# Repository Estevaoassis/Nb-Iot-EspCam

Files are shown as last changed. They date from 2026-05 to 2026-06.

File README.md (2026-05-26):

# PROT-TIPO-PARA-CAPTURA-E-TRANSMISS-O-DE-IMAGENS-DE-BAIXA-RESOLU-O-UTILIZANDO-CAT-NB2
Protótipo embarcado para captura e transmissão de imagens de baixa resolução via rede Cat NB2, com foco em baixo consumo energético e conectividade IoT. O sistema utiliza câmera compacta, compressão de dados e envio eficiente para monitoramento remoto em áreas com cobertura limitada.

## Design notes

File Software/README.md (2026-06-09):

# ESP-CAM IoT Image Receiver & Dashboard

Este repositório contém o software completo (Backend, Banco de Dados e Frontend) responsável por receber, processar, armazenar e exibir imagens transmitidas por um dispositivo ESP32-CAM através de redes IoT (NB-IoT/MQTT ou Serial).

## O que o sistema faz?
1. **MQTT Receiver:** Fica escutando um Broker MQTT por fragmentos de imagem (*chunks*) enviados pela placa.
2. **Reconstrução:** Ao receber todos os *chunks*, ele monta a imagem (seja formato JPEG padrão ou Grayscale/Raw).
3. **Persistência Dupla:** Salva o arquivo de imagem fisicamente na pasta `output/` e armazena a versão codificada e seus metadados diretamente no banco de dados **MongoDB**.
4. **Web Dashboard:** Disponibiliza uma página web sofisticada para visualização das imagens capturadas em tempo real.

---

## Estrutura do Projeto

- `config/`: Configurações globais do projeto (variáveis de banco, porta serial, host MQTT).
- `core/`: 
  - `db_manager.py`: Comunicação com o MongoDB (inserção e consulta).
  - `image_processor.py` / `serial_comm.py`: Processamento e comunicação.
- `scripts/`: 
  - `mqtt_receiver.py`: Serviço em segundo plano que recebe as fotos pelo MQTT.
  - `web_dashboard.py`: Servidor Web em Flask para a interface visual.
- `web/`: Código-fonte do Frontend (HTML5 / CSS3 Moderno com *Glassmorphism*).
- `output/`: Diretório onde as imagens brutas são espelhadas localmente.
- `docker-compose.yml` e `Dockerfile`: Arquivos para subir e orquestrar a infraestrutura toda com o Docker.

---

## Como Rodar (Usando Docker - Recomendado)

A forma mais fácil e recomendada de rodar todo esse sistema de uma vez (banco de dados, receptor e dashboard) é utilizando o **Docker Compose**.

### Pré-requisitos
- [Docker Desktop](https://www.docker.com/products/docker-desktop) instalado e rodando.

### Iniciando a Infraestrutura

1. Abra o terminal na raiz desta pasta (`Software/`).
2. Execute o comando para construir as imagens e subir os três containers em segundo plano:
   ```bash
   docker-compose up --build -d
   ```

3. **Acompanhar os logs:**
   Se quiser ver as conexões MQTT sendo feitas e os chunks chegando em tempo real, use:
   ```bash
   docker-compose logs -f app
   ```

4. **Acessar o Web Dashboard:**
   Abra seu navegador e acesse: 👉 **http://localhost:5000**

---

## Como Rodar (Manual / Sem Docker)

Caso prefira rodar apenas scripts locais usando um ambiente virtual (`venv`), siga os passos:

1. **Crie e ative o ambiente virtual:**
   ```bash
   python -m venv .venv
   
   # No Windows:
   .venv\Scripts\activate
   # No Linux/Mac:
   source .venv/bin/activate
   ```

2. **Instale as dependências:**
   ```bash
   pip install -r requirements.txt
   ```

3. **Inicie o Receptor MQTT:**
   *(Nota: O MongoDB precisa estar rodando localmente na porta 27017, caso contrário a imagem será salva apenas na pasta `output/`)*
   ```bash
   python -m scripts.mqtt_receiver
   ```

4. **Inicie o Servidor do Web Dashboard:** (Abra em outro terminal com o `.venv` ativado)
   ```bash
   python -m scripts.web_dashboard
   ```

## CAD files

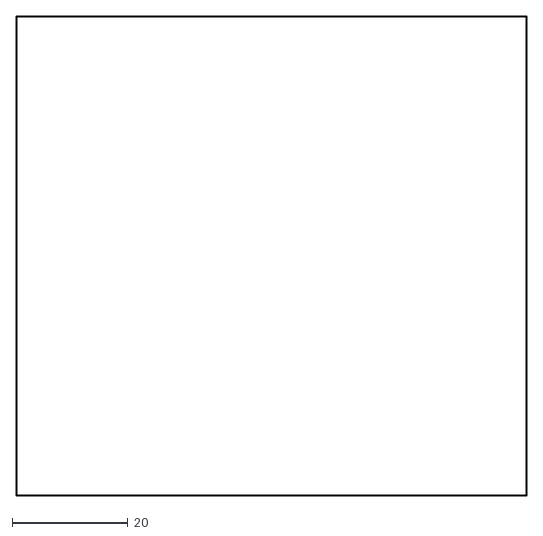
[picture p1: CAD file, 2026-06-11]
Hardware/Output/Nb-board-Edge_Cuts.dxf
88.3 x 82.9

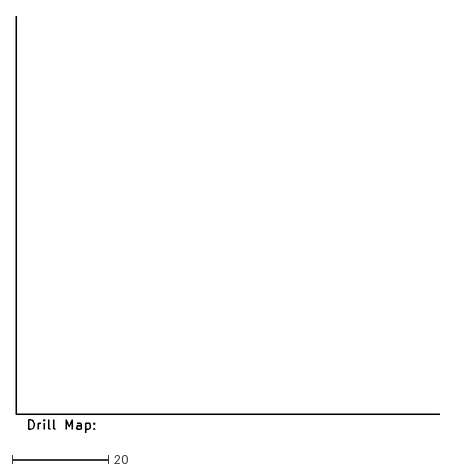
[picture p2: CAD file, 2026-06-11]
Hardware/Output/Nb-board-NPTH-drl_map.dxf
88.2 x 86.7

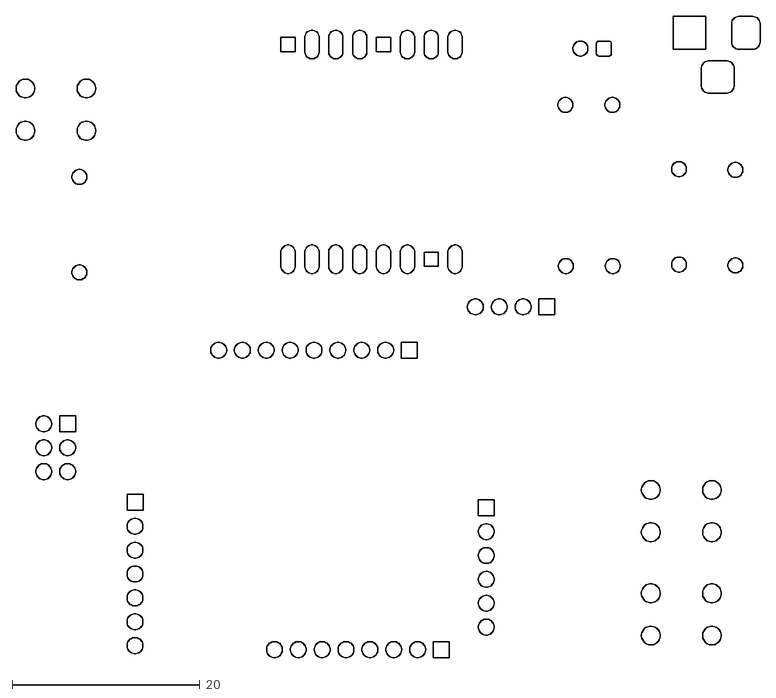
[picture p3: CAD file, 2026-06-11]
Hardware/Output/Nb-board-B_Cu.dxf
79.2 x 68.3

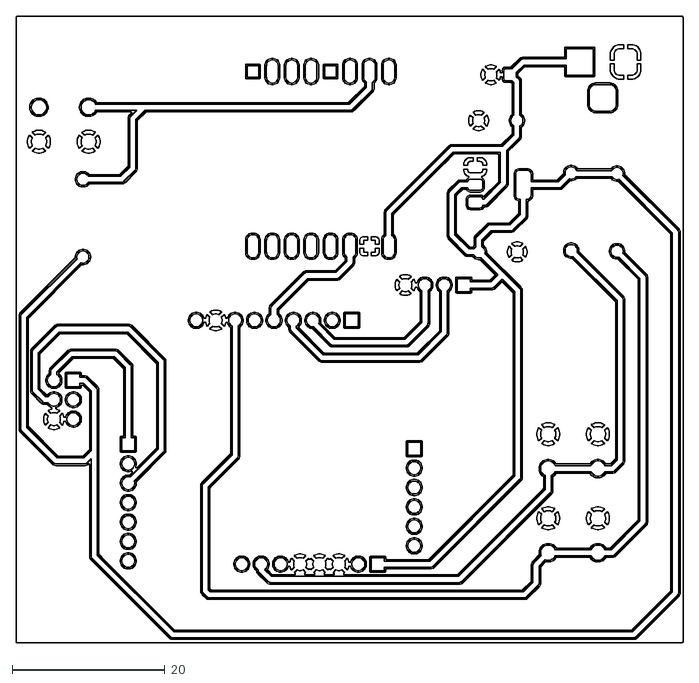
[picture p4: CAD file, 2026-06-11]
Hardware/Output/Nb-board-F_Cu.dxf
87.2 x 81.9

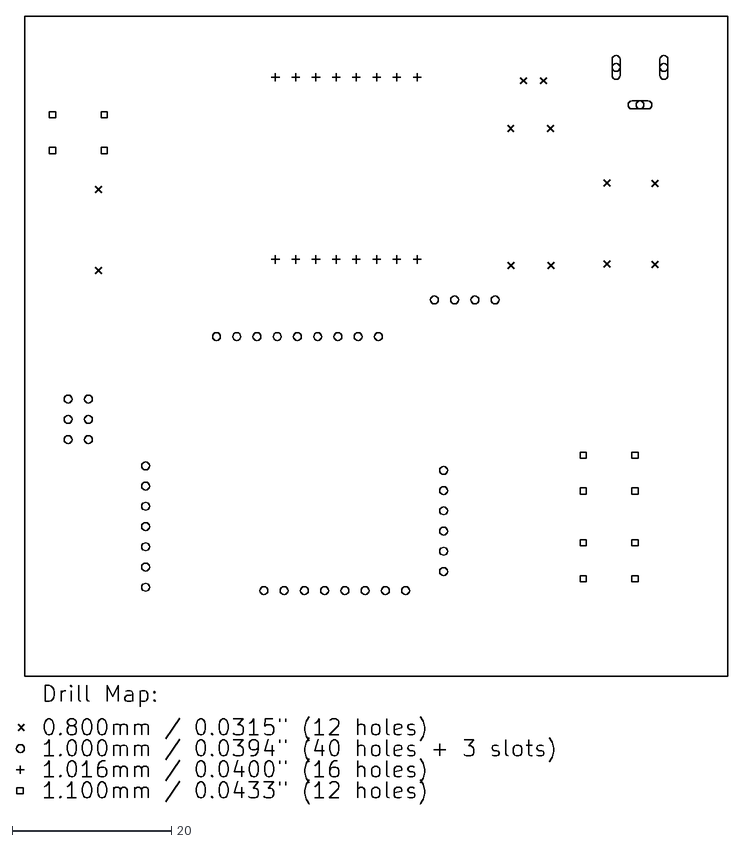
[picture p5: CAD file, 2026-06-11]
Hardware/Output/Nb-board-PTH-drl_map.dxf
89.3 x 98.9

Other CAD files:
Hardware/Output/Nb-board-B_Mask.dxf
Hardware/Output/Nb-board-B_Paste.dxf
Hardware/Output/Nb-board-F_Mask.dxf
Hardware/Output/Nb-board-F_Paste.dxf

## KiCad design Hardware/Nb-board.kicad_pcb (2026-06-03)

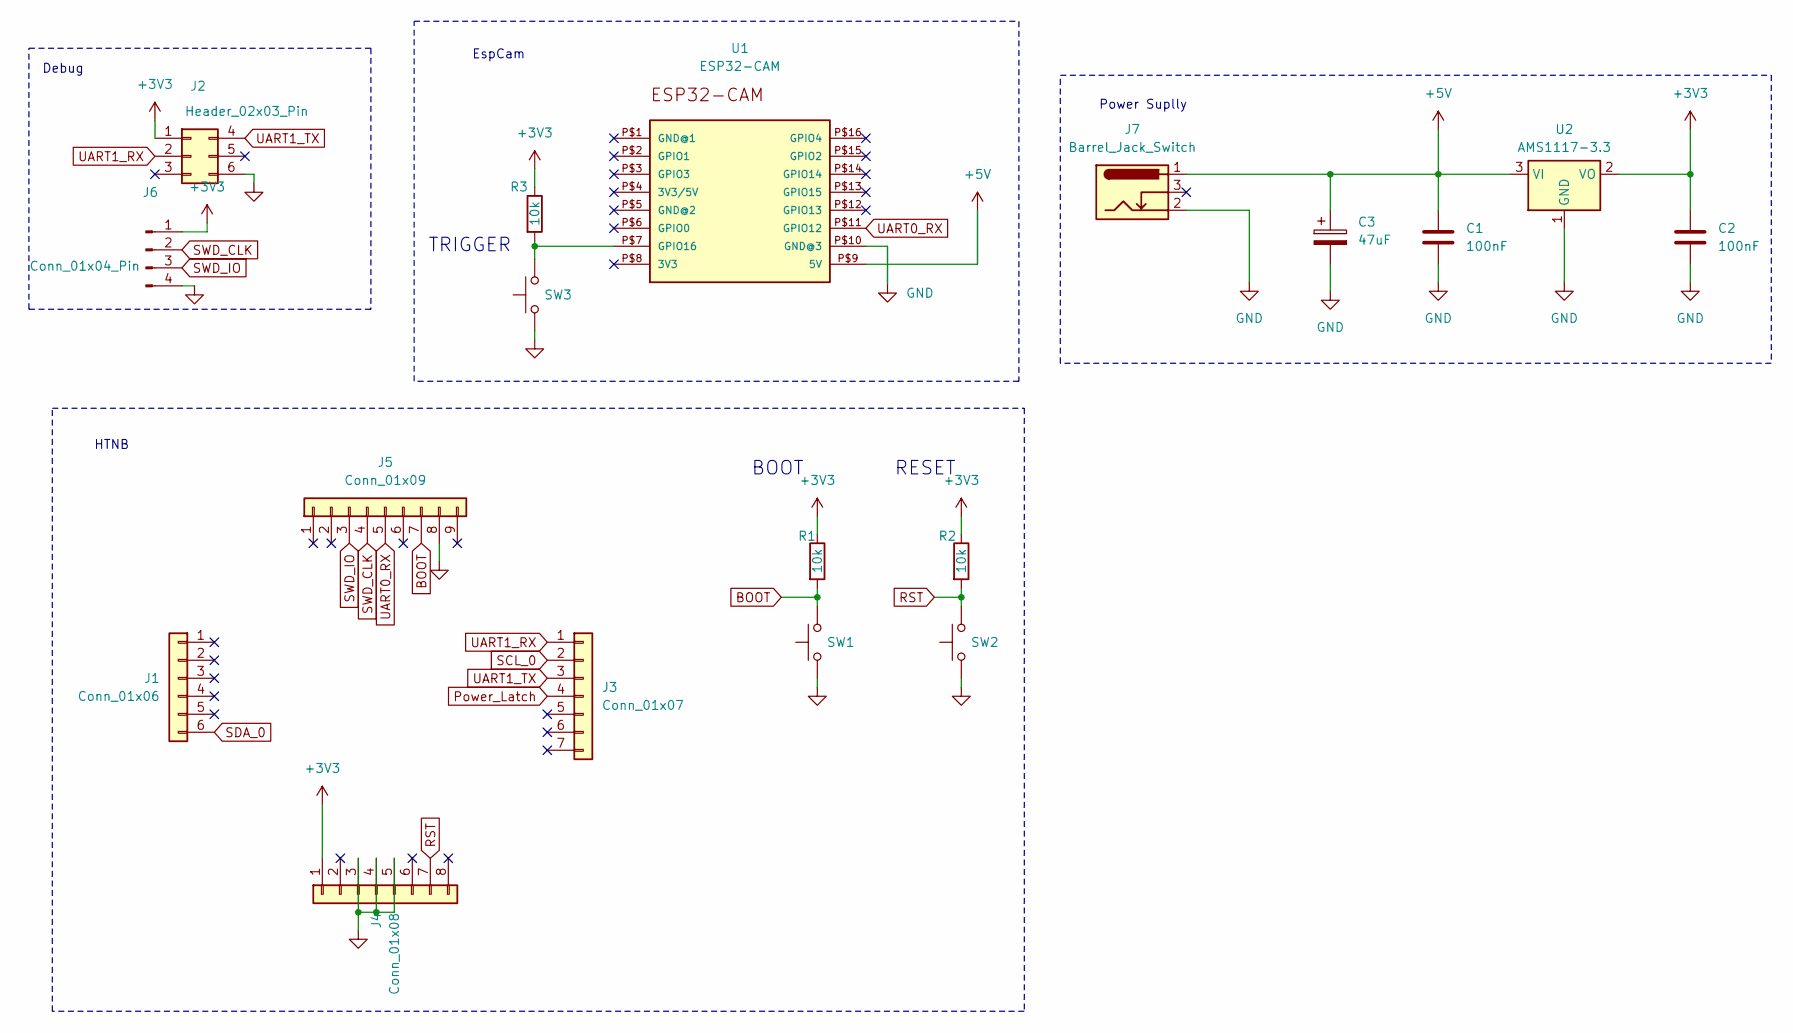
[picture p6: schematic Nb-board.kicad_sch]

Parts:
C1, C2: 100nF; C_Disc_D5.0mm_W2.5mm_P5.00mm
C3: 47uF; CP_Radial_D5.0mm_P2.50mm
J1: Conn_01x06; PinSocket_1x06_P2.54mm_Vertical
J2: Header_02x03_Pin; PinHeader_2x03_P2.54mm_Vertical
J3: Conn_01x07; PinSocket_1x07_P2.54mm_Vertical
J4: Conn_01x08; PinSocket_1x08_P2.54mm_Vertical
J5: Conn_01x09; PinSocket_1x09_P2.54mm_Vertical
J6: Conn_01x04_Pin; PinHeader_1x04_P2.54mm_Vertical
J7: Barrel_Jack_Switch; BarrelJack_Horizontal
R1, R2, R3: 10k; R_Axial_DIN0207_L6.3mm_D2.5mm_P10.16mm_Horizontal
SW1, SW2, SW3: SW_Push; SW_PUSH_6mm
U1: ESP32-CAM
U2: AMS1117-3.3; SOT-223-3_TabPin2

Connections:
+3V3: C2.1, J2.1, J4.1, J6.1, R1.1, R2.1, R3.1, U2.2 (VO)
+5V: C1.1, C3.1, J7.1, U1.P$9 (5V), U2.3 (VI)
BOOT: J5.7, R1.2, SW1.2
GND: C1.2, C2.2, C3.2, J2.6, J4.3, J4.4, J4.5, J5.8, J6.4, J7.2, SW1.1, SW2.1, SW3.1, U1.P$10 (GND@3), U2.1 (GND)
unnamed: R3.2, SW3.2, U1.P$7 (GPIO16)
Power_Latch: J3.4
RST: J4.7, R2.2, SW2.2
SCL_0: J3.2
SDA_0: J1.6
SWD_CLK: J5.4, J6.2
SWD_IO: J5.3, J6.3
UART0_RX: J5.5, U1.P$11 (GPIO12)
UART1_RX: J2.2, J3.1
UART1_TX: J2.4, J3.3

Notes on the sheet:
RESET
HTNB
Debug
TRIGGER
EspCam
BOOT
Power Suplly

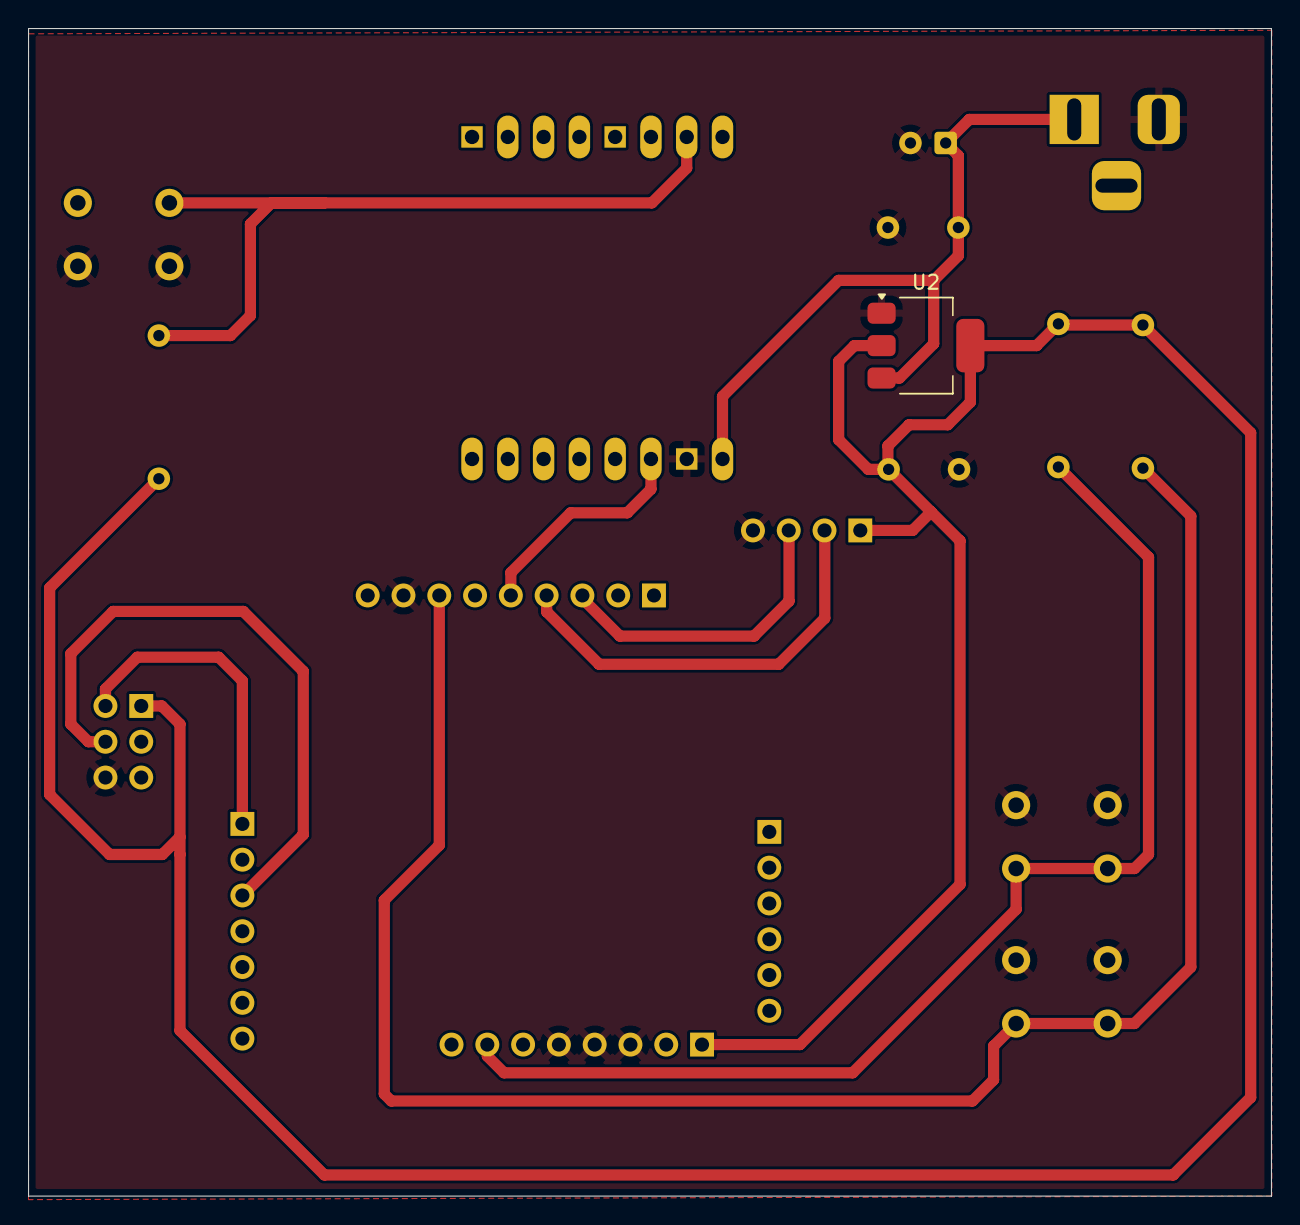
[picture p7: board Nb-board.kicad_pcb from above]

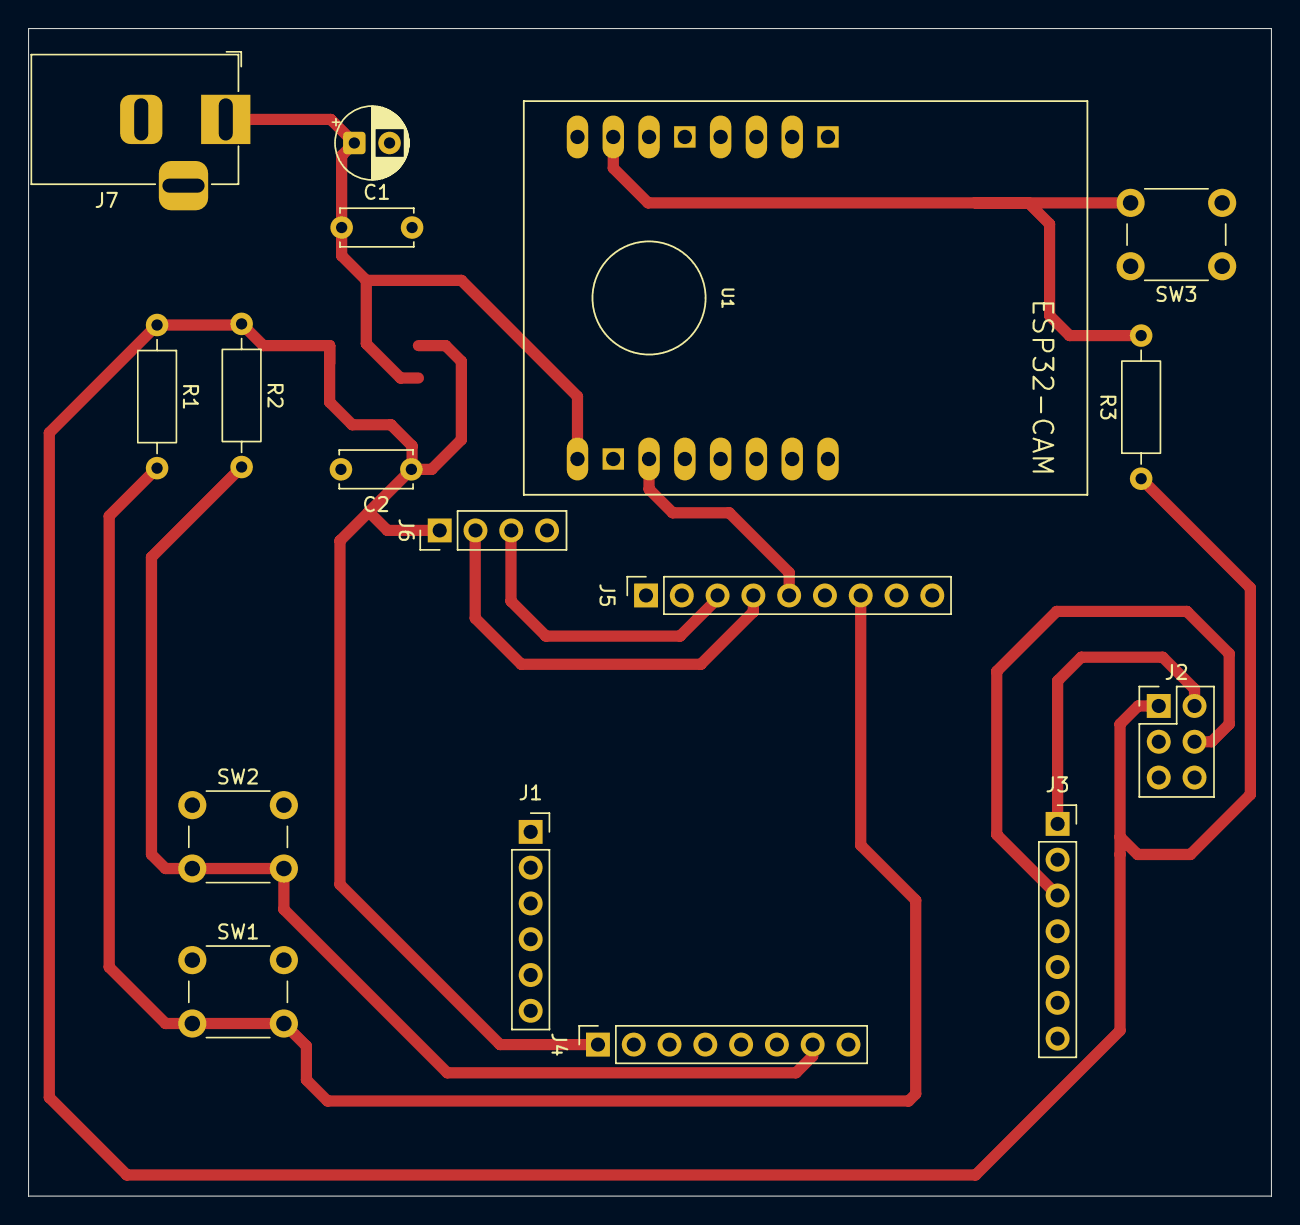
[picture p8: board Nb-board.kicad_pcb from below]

Board: 2 copper layers, 88.2 x 82.9 mm, 18 parts (17 on the bottom side), 11 nets.

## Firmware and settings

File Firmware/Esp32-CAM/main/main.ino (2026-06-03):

/**************************
 * Copyright © 2025 LAB 14.0 - UEA Universidade do Estado do Estado do Amazonas
 * All rights reserved
 **************************/

#include <Arduino.h>
#include "esp_camera.h"
#include <HardwareSerial.h>
#include "soc/soc.h"
#include "soc/rtc_cntl_reg.h"

// --- Pinos AI-Thinker ---
#define PWDN_GPIO_NUM 32
#define RESET_GPIO_NUM -1
#define XCLK_GPIO_NUM 0
#define SIOD_GPIO_NUM 26
#define SIOC_GPIO_NUM 27
#define Y9_GPIO_NUM 35
#define Y8_GPIO_NUM 34
#define Y7_GPIO_NUM 39
#define Y6_GPIO_NUM 36
#define Y5_GPIO_NUM 21
#define Y4_GPIO_NUM 19
#define Y3_GPIO_NUM 18
#define Y2_GPIO_NUM 5
#define VSYNC_GPIO_NUM 25
#define HREF_GPIO_NUM 23
#define PCLK_GPIO_NUM 22

// --- Constantes do Sistema ---
const int kChunkSize = 512;
const uint8_t kIdFoto = 0xAA;
const int kRxPin = 12;
const int kTxPin = 13;
const int kBaudRate = 115200; // Deve ser 115200 para sincronizar com a placa HTNB32L

// Inicializa a UART1 para comunicação com o módulo NB-IoT
HardwareSerial SerialApp(1);

void InitCamera()
{
  camera_config_t config;
  config.ledc_channel = LEDC_CHANNEL_0;
  config.ledc_timer = LEDC_TIMER_0;
  config.pin_d0 = Y2_GPIO_NUM;
  config.pin_d1 = Y3_GPIO_NUM;
  config.pin_d2 = Y4_GPIO_NUM;
  config.pin_d3 = Y5_GPIO_NUM;
  config.pin_d4 = Y6_GPIO_NUM;
  config.pin_d5 = Y7_GPIO_NUM;
  config.pin_d6 = Y8_GPIO_NUM;
  config.pin_d7 = Y9_GPIO_NUM;
  config.pin_xclk = XCLK_GPIO_NUM;
  config.pin_pclk = PCLK_GPIO_NUM;
  config.pin_vsync = VSYNC_GPIO_NUM;
  config.pin_href = HREF_GPIO_NUM;
  config.pin_sscb_sda = SIOD_GPIO_NUM;
  config.pin_sscb_scl = SIOC_GPIO_NUM;
  config.pin_pwdn = PWDN_GPIO_NUM;
  config.pin_reset = RESET_GPIO_NUM;

  // Clock mais baixo (10MHz) para maior estabilidade elétrica
  config.xclk_freq_hz = 10000000;
  config.pixel_format = PIXFORMAT_GRAYSCALE;
  config.frame_size = FRAMESIZE_QQVGA; // 160x120
  config.fb_count = 1;

  esp_err_t err = esp_camera_init(&config);
  if (err != ESP_OK)
  {
    Serial.printf("Erro na inicializacao da camera: 0x%x\n", err);
    return;
  }
  Serial.println("Camera inicializada com sucesso.");
}

void setup()
{
  // Mata o Brownout logo no início para evitar Reboot
  WRITE_PERI_REG(RTC_CNTL_BROWN_OUT_REG, 0);

  // UART0: Debug no PC (conexão direta)
  Serial.begin(kBaudRate);

  // UART1: Comunicação com o módulo NB-IoT
  SerialApp.begin(kBaudRate, SERIAL_8N1, kRxPin, kTxPin);

  delay(500);
  Serial.println("\n--- INICIANDO SISTEMA ---");
  InitCamera();
}

void loop()
{
  Serial.println("\nAguardando comando 'OK' na porta serial para capturar imagem...");

  // Aguarda até receber dados na serial
  while (Serial.available() == 0)
  {
    delay(100);
  }

  // Lê a string recebida
  String cmd = Serial.readString();
  cmd.trim();

  if (cmd.equalsIgnoreCase("OK"))
  {
    Serial.println("Comando 'OK' recebido! Capturando imagem...");
    delay(1000); // Pequeno atraso antes da captura

    camera_fb_t *fb = esp_camera_fb_get();
    if (!fb)
    {
      Serial.println("Erro ao pegar buffer do frame!");
      return;
    }

    // Lógica de Fatiamento para NB-IoT
    int totalLen = fb->len;
    int numPacotes = (totalLen + kChunkSize - 1) / kChunkSize;

    for (int i = 0; i < numPacotes; i++)
    {
      int offset = i * kChunkSize;
      int size = (totalLen - offset > kChunkSize) ? kChunkSize : (totalLen - offset);

      // LOG: Mostra no monitor serial o progresso
      Serial.printf("Enviando PKT:%d/%d | OFF:%d | LEN:%d\n", i + 1, numPacotes, offset, size);

      // PAYLOAD: Envia os dados pela UART1 (SerialApp) para o modem
      for (int j = 0; j < size; j++)
      {
        int idxGlobal = offset + j;
        uint8_t pixel = fb->buf[idxGlobal];
        if (pixel < 0x10)
        {
          SerialApp.print("0");
          Serial.print("0"); // Envia para o cabo do PC para visualização
        }
        SerialApp.print(pixel, HEX);
        Serial.print(pixel, HEX); // Envia para o cabo do PC
      }
      SerialApp.println();
      Serial.println();

      // Delay otimizado de 300ms para estabilidade do buffer e rede celular
      delay(300);
    }

    esp_camera_fb_return(fb);
    Serial.println("\n--- FIM DA TRANSMISSAO ---");
  }
  else
  {
    Serial.printf("Comando desconhecido recebido: '%s'\n", cmd.c_str());
  }

  // Limpa qualquer lixo que tenha ficado na serial (ex: enters sobrando)
  while (Serial.available() > 0)
  {
    Serial.read();
  }
}

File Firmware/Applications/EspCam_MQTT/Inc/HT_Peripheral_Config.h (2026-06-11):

/*

  _    _ _______   __  __ _____ _____ _____   ____  _   _
 | |  | |__   __| |  \/  |_   _/ ____|  __ \ / __ \| \ | |
 | |__| |  | |    | \  / | | || |    | |__) | |  | |  \| |
 |  __  |  | |    | |\/| | | || |    |  _  /| |  | | . ` |
 | |  | |  | |    | |  | |_| || |____| | \ \| |__| | |\  |
 |_|  |_|  |_|    |_|  |_|_____\_____|_|  \_\\____/|_| \_|
 =================== Advanced R&D ========================

 Copyright (c) 2023 HT Micron Semicondutores S.A.
 Licensed under the Apache License, Version 2.0 (the "License");
 you may not use this file except in compliance with the License.
 You may obtain a copy of the License at
 http://www.apache.org/licenses/LICENSE-2.0
 Unless required by applicable law or agreed to in writing, software
 distributed under the License is distributed on an "AS IS" BASIS,
 WITHOUT WARRANTIES OR CONDITIONS OF ANY KIND, either express or implied.
 See the License for the specific language governing permissions and
 limitations under the License.

*/

/*!
 * \file HT_Peripheral_Config.h
 * \brief Peripheral configuration for MQTT Example.
  * \author HT Micron Advanced R&D,
 *         Hêndrick Bataglin Gonçalves, Christian Roberto Lehmen,  Matheus da Silva Zorzeto, Felipe Kalinski Ferreira,
 *         Leandro Borges, Mauricio Carlotto Ribeiro, Henrique Kuhn, Cleber Haack, Eduardo Mendel
 *         Gleiser Alvarez Arrojo
 * 
 * \link https://github.com/htmicron
 * \version 0.1
 * \date September 15, 2023
 */

#ifndef __HT_PERIPHERAL_CONFIG_H__
#define __HT_PERIPHERAL_CONFIG_H__

#include "qcx212.h"

/*
----------------------------------------------------  Table 1. GPIO Table. -------------------------------------------------------------
___________________________________________________________________________________________________________________________________________________________________________________________
| Pad ID |       GPIO Number    |  Pin Number  | Instance | Pull (default:options) |       AF0      |      AF1      |    AF2      |      AF3      |  AF4 |   AF5  |   AF6  |      AF7      |
|--------|----------------------|--------------|----------|------------------------|----------------|---------------|-------------|---------------|------|--------|--------|---------------|
|   12   |        GPIO1         |      1       |    0     |      B-PU:nppd         |  GPIO1         |      –	      |  UART2_TXD  |      –        |   –  |    –   |    –   |      –        | 
|   13   |        GPIO2         |      2       |    0     |      B-PU:nppd         |  GPIO2/Timer0  |  UART0_RTSn   |  UART2_RXD  |    SPI1_SSn0  |   –  |  PWM0  |    –   |      –        |
|   14   |        GPIO3         |      3       |    0     |      B-PU:nppd         |  GPIO3         |  UART0_CTSn   |  UART2_TXD  |    SPI1_MOSI  |   –  |  PWM1  |    –   |      –        |
|   15   |        GPIO4         |      4       |    0     |      B-PU:nppd         |  GPIO4         |  UART0_RXD    |  I2C1_SDA   |    SPI1_MISO  |   –  |  PWM2  |    –   |      –        |
|   16   |        GPIO5         |      5       |    0     |      B-PU:nppd         |  GPIO5         |  UART0_TXD    |  I2C1_SCL   |    SPI1_SCLK  |   –  |  PWM3  |    –   |      –        |
|   17   |        GPIO6         |      6       |    0     |      B-PU:nppd         |  GPIO6/Timer1  |  SPI0_SSn0    |  I2C0_SDA   |    UART1_RTSn |   –  |  PWM4  |    –   |      –        |
|   18   |        GPIO7         |      7       |    0     |      B-PU:nppd         |  GPIO7         |  SPI0_MOSI    |  I2C0_SCL   |    UART1_CTSn |   –  |  PWM5  |    –   |      –        |
|   19   |        GPIO13        |      13      |    0     |      B-PU:nppd         |  GPIO13        |  SPI0_MISO    |  I2C1_SDA   |    UART1_RXD  |   –  |  PWM0  |    –   |      –        |
|   20   |        GPIO12        |      12      |    0     |      B-PU:nppd         |  GPIO12        |  SPI0_SCLK    |  I2C1_SCL   |    UART1_TXD  |   –  |  PWM1  |    –   |      –        |
|   25   |        GPIO10        |      10      |    0     |      B-PU:nppd         |  GPIO10/Timer3 |  I2C0_SCL     |      –      |    SPI1_SSn1  |   –  |  PWM0  |    –   |      –        |
|   9    |        SWCLK         |      2       |    1     |      B-PU:nppd         |  SWCLK         |      –        |  UART2_RXD  |    UART1_RTSn |   –  |  PWM4  |    –   |    GPIO18     |
|   10   |        SWDIO         |      3       |    1     |      B-PU:nppd         |  SWDIO         |      –        |  UART2_TXD  |    UART1_CTSn |   –  |  PWM5  |    –   |    GPIO19     |
|   31   |   AON_GPIO0 (GPIO20)	|      4       |    1     |      DIO-PD:nppu       |  GPIO20/Timer5 |      –        |      –      |      –        |   –  |    –   |    –   |      –        |
____________________________________________________________________________________________________________________________________________________________________________________________
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

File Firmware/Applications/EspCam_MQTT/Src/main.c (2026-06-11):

/**
 *
 * Copyright (c) 2023 HT Micron Semicondutores S.A.
 * Licensed under the Apache License, Version 2.0 (the "License");
 * you may not use this file except in compliance with the License.
 * You may obtain a copy of the License at
 * http://www.apache.org/licenses/LICENSE-2.0
 * Unless required by applicable law or agreed to in writing, software
 * distributed under the License is distributed on an "AS IS" BASIS,
 * WITHOUT WARRANTIES OR CONDITIONS OF ANY KIND, either express or implied.
 * See the License for the specific language governing permissions and
 * limitations under the License.
 *
 */

#include "main.h"
#include "ps_lib_api.h"
#include "flash_qcx212.h"

static StaticTask_t initTask;
static uint8_t appTaskStack[INIT_TASK_STACK_SIZE];
static volatile uint32_t Event;
static QueueHandle_t psEventQueueHandle;
static uint8_t gImsi[16] = {0};
static uint32_t gCellID = 0;
static NmAtiSyncRet gNetworkInfo;
static uint8_t mqttEpSlpHandler = 0xff;

static volatile uint8_t simReady = 0;

static uint32_t uart_cntrl = (ARM_USART_MODE_ASYNCHRONOUS | ARM_USART_DATA_BITS_8 | ARM_USART_PARITY_NONE |
                              ARM_USART_STOP_BITS_1 | ARM_USART_FLOW_CONTROL_NONE);

trace_add_module(APP, P_INFO);

extern void mqtt_demo_onenet(void);

extern USART_HandleTypeDef huart0;
extern USART_HandleTypeDef huart1;

static void HT_SetConnectioParameters(void)
{
    uint8_t cid = 0;
    PsAPNSetting apnSetting;
    int32_t ret;
    uint8_t networkMode = 0; //nb-iot network mode
    uint8_t bandNum = 1;
    uint8_t band = 28;

    ret = appSetBandModeSync(networkMode, bandNum, &band);
    if (ret == CMS_RET_SUCC)
    {
        printf("SetBand Result: %d\n", ret);
    }

    apnSetting.cid = 0;
    apnSetting.apnLength = strlen("nbiot.gsim");
    strcpy((char *)apnSetting.apnStr, "nbiot.gsim");
    apnSetting.pdnType = CMI_PS_PDN_TYPE_IP_V4V6;
    ret = appSetAPNSettingSync(&apnSetting, &cid);
}

static void sendQueueMsg(uint32_t msgId, uint32_t xTickstoWait)
{
    eventCallbackMessage_t *queueMsg = NULL;
    queueMsg = malloc(sizeof(eventCallbackMessage_t));
    queueMsg->messageId = msgId;
    if (psEventQueueHandle)
    {
        if (pdTRUE != xQueueSend(psEventQueueHandle, &queueMsg, xTickstoWait))
        {
            HT_TRACE(UNILOG_MQTT, mqttAppTask80, P_INFO, 0, "xQueueSend error");
        }
    }
}

static INT32 registerPSUrcCallback(urcID_t eventID, void *param, uint32_t paramLen)
{
    CmiSimImsiStr *imsi = NULL;
    CmiPsCeregInd *cereg = NULL;
    UINT8 rssi = 0;
    NmAtiNetifInfo *netif = NULL;

    switch (eventID)
    {
    case NB_URC_ID_SIM_READY:
    {
        imsi = (CmiSimImsiStr *)param;
        memcpy(gImsi, imsi->contents, imsi->length);
        simReady = 1;
        break;
    }
    case NB_URC_ID_MM_SIGQ:
    {
        rssi = *(UINT8 *)param;
        HT_TRACE(UNILOG_MQTT, mqttAppTask81, P_INFO, 1, "RSSI signal=%d", rssi);
        break;
    }
    case NB_URC_ID_PS_BEARER_ACTED:
    {
        HT_TRACE(UNILOG_MQTT, mqttAppTask82, P_INFO, 0, "Default bearer activated");
        break;
    }
    case NB_URC_ID_PS_BEARER_DEACTED:
    {
        HT_TRACE(UNILOG_MQTT, mqttAppTask83, P_INFO, 0, "Default bearer Deactivated");
        break;
    }
    case NB_URC_ID_PS_CEREG_CHANGED:
    {
        cereg = (CmiPsCeregInd *)param;
        gCellID = cereg->celId;
        HT_TRACE(UNILOG_MQTT, mqttAppTask84, P_INFO, 4, "CEREG changed act:%d celId:%d locPresent:%d tac:%d", cereg->act, cereg->celId, cereg->locPresent, cereg->tac);
        break;
    }
    case NB_URC_ID_PS_NETINFO:
    {
        netif = (NmAtiNetifInfo *)param;
        if (netif->netStatus == NM_NETIF_ACTIVATED)
            sendQueueMsg(QMSG_ID_NW_IPV4_READY, 0);
        break;
    }

    default:
        break;
    }
    return 0;
}

static void HT_MQTTExampleTask(void *arg)
{
    int32_t ret;
    uint8_t psmMode = 0, actType = 0;
    uint16_t tac = 0;
    uint32_t tauTime = 0, activeTime = 0, cellID = 0, nwEdrxValueMs = 0, nwPtwMs = 0;

    eventCallbackMessage_t *queueItem = NULL;

    registerPSEventCallback(NB_GROUP_ALL_MASK, registerPSUrcCallback);
    psEventQueueHandle = xQueueCreate(APP_EVENT_QUEUE_SIZE, sizeof(eventCallbackMessage_t *));
    if (psEventQueueHandle == NULL)
    {
        HT_TRACE(UNILOG_MQTT, mqttAppTask0, P_INFO, 0, "psEventQueue create error!");
        return;
    }

    slpManApplyPlatVoteHandle("EP_MQTT", &mqttEpSlpHandler);
    slpManPlatVoteDisableSleep(mqttEpSlpHandler, SLP_ACTIVE_STATE); //SLP_SLP2_STATE
    HT_TRACE(UNILOG_MQTT, mqttAppTask1, P_INFO, 0, "first time run mqtt example");

    HAL_USART_InitPrint(&huart1, GPR_UART1ClkSel_26M, uart_cntrl, 115200);
    printf("HTNB32L-XXX MQTT Example!\n");
    printf("Trying to connect...\n");
    while (!simReady)
        ;
    HT_SetConnectioParameters();

    while (1)
    {
        if (xQueueReceive(psEventQueueHandle, &queueItem, portMAX_DELAY))
        {
            switch (queueItem->messageId)
            {
            case QMSG_ID_NW_IPV4_READY:
            case QMSG_ID_NW_IPV6_READY:
            case QMSG_ID_NW_IPV4_6_READY:
                appGetImsiNumSync((CHAR *)gImsi);
                HT_STRING(UNILOG_MQTT, mqttAppTask2, P_SIG, "IMSI = %s", gImsi);

                appGetNetInfoSync(gCellID, &gNetworkInfo);
                if (NM_NET_TYPE_IPV4 == gNetworkInfo.body.netInfoRet.netifInfo.ipType)
                    HT_TRACE(UNILOG_MQTT, mqttAppTask3, P_INFO, 4, "IP:\"%u.%u.%u.%u\"", ((UINT8 *)&gNetworkInfo.body.netInfoRet.netifInfo.ipv4Info.ipv4Addr.addr)[0],
                             ((UINT8 *)&gNetworkInfo.body.netInfoRet.netifInfo.ipv4Info.ipv4Addr.addr)[1],
                             ((UINT8 *)&gNetworkInfo.body.netInfoRet.netifInfo.ipv4Info.ipv4Addr.addr)[2],
                             ((UINT8 *)&gNetworkInfo.body.netInfoRet.netifInfo.ipv4Info.ipv4Addr.addr)[3]);
                ret = appGetLocationInfoSync(&tac, &cellID);
                HT_TRACE(UNILOG_MQTT, mqttAppTask4, P_INFO, 3, "tac=%d, cellID=%d ret=%d", tac, cellID, ret);
                //edrxModeValue = CMI_MM_ENABLE_EDRX_AND_ENABLE_IND;
                actType = CMI_MM_EDRX_NB_IOT;
                //reqEdrxValueMs = 20480;
                // appSetEDRXSettingSync(edrxModeValue, actType, reqEdrxValueMs);
                ret = appGetEDRXSettingSync(&actType, &nwEdrxValueMs, &nwPtwMs);
                HT_TRACE(UNILOG_MQTT, mqttAppTask5, P_INFO, 4, "actType=%d, nwEdrxValueMs=%d nwPtwMs=%d ret=%d", actType, nwEdrxValueMs, nwPtwMs, ret);

                psmMode = 1;
                tauTime = 4000;
                activeTime = 30;

                {
                    appGetPSMSettingSync(&psmMode, &tauTime, &activeTime);
                    HT_TRACE(UNILOG_MQTT, mqttAppTask6, P_INFO, 3, "Get PSM info mode=%d, TAU=%d, ActiveTime=%d", psmMode, tauTime, activeTime);
                }

                HT_USART_InitApp();
                HT_Fsm();
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

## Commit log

2026-05-27 Add initial implementation of camera functionality and create README files for documentation
2026-06-03 feat: add Nb-board v1.0
    [Nb-board.kicad_pcb, Nb-board.kicad_sch]
2026-06-03 feat: reintroduce main.ino for camera initialization and image transmission; update settings for serial communication
2026-06-04 feat: add mqtt_receiver script to reconstruct and save fragmented images from ESP32-CAM
2026-06-11 feat: add project kicad 9.0 board to HTNB32L
    [Nb-board-B_Cu.dxf, Nb-board-B_Mask.dxf, Nb-board-B_Paste.dxf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]
